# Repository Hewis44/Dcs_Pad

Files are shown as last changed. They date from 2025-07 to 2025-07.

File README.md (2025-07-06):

## DCS World Macropad – “Sukhoi Control Pad” by Hewis Lamilton

## Please Dont consider this as macropad i have made a custom rp2040 for this - its a production level Macropad specially made for music,games




So yeah, I’ve been flying around in DCS World for a while now, mostly in the Su-27 and F/A-18, and it was just super annoying trying to hit 20 keyboard shortcuts every time I wanted to fire a missile, toggle flaps, or adjust trim. I got tired of fumbling keys and decided to just make my own macropad — something that feels like it belongs in a real cockpit. This whole project is my attempt to bring that control panel vibe right onto my desk, with the clickiness and smooth analog feel you only get from physical controls.



I didn’t want to go for those premade macro boards or overpriced HOTAS setups. Instead, I designed my own PCB from scratch using EasyEDA, placed the components carefully, routed everything, added some fighter jet graphics and even stamped my name on it — “MADE BY HEWIS LAMILTON” — just for that personal flex. The board has 9 mechanical switches arranged in a 3x3 grid and 3 rotary encoders at the top for analog input like radar zoom, trims or throttle. These encoders also have push buttons, so they double as click inputs when needed.




The core of the board is powered by the RP2040 microcontroller, soldered during the PCBA process done at JLCPCB. I skipped the Arduino Pro Micro this time because RP2040 is just too good — it gives more performance, is widely supported, and is future-proof. I got two boards assembled (bottom side SMT) from JLC, which means all the micro stuff and passives are already done, so now I just need to add the switches and encoders by hand. I made the board hotswappable using Kailh sockets, so I can just pop switches in and out without worrying about soldering. Makes life easy, especially if you like experimenting with switch feel.







The case design was done in Fusion 360 and looks pretty sleek — all black, with curved corners and a low profile. I’ll probably 3D print it with matte black PLA or maybe even make it from leftover acrylic sheets from my old FPV drone projects. The USB port is Type-C, of course micro-USB is mid and breaks too often. And yes, I’m flashing it with QMK firmware once it arrives. Since QMK now supports RP2040, I can map each key and encoder action to whatever DCS command I want — radar lock, missile launch, you name it.



###  Bill of Materials (Premium Build – ₹11,180 / $124.05)

| **Component** | **Source & Link** | **Qty** | **Total Cost (INR)** | **Total Cost (USD)** |
|---|---|---:|---:|---:|
| Rotary Encoders | [neomacro.in](https://neomacro.in) | 3 | ₹630 | $7.40 |
| Encoder Knobs (Metal) | [neomacro.in](https://neomacro.in) | 3 | ₹270 | $3.17 |
| Mechanical Switches (Gateron G Pro 3.0) | [Amazon.in – Gateron Blue (72-pack)](https://www.amazon.in/dp/B0C6V34QMW) | 9 | ₹663 | $7.80 |
| Hot-swap Sockets (Kailh) | [neomacro.in](https://neomacro.in) | 9 | ₹450 | $5.30 |
| Keycaps (PBT Black/Grey) | [neomacro.in](https://neomacro.in) | 9 | ₹670 | $7.90 |
| Custom PCB (5 pcs) | [neomacro.in](https://neomacro.in) – powered by JLCPCB | 5 | ₹1,950 | $23.39 |
| PCBA (SMT) (2 pcs) |  JLCPCB | 1 | ₹3,550 | $42.47 |
| Shipping (Combined) | Jlcpcb | 1 | ₹1,770 | $21.20 |
| Case (OPTIONAL 3D Printed Frame) | PLA FILAMENT( HAVE PRINTER) | 1 | ₹600 | $7.50 |
---

###  **Total Cost**

**INR:** ₹11,180  
**USD:** $124.05



The total estimated cost of the entire build comes out to approximately $123.68, which in Indian rupees is roughly ₹10,600 based on a dollar rate of ₹85. This includes everything — PCB fabrication, PCBA service, components, and shipping.

Visually, it looks super clean. The PCB has black solder mask, aircraft graphics on the silkscreen, and that Sukhoi logo adds serious style. It's not just a functional tool — it actually looks like a part of the cockpit. The renders turned out mad good too, and I can already imagine how cool it’ll feel mounted next to my keyboard during a dogfight.

To be honest, this is not just a project. It’s a passion piece. Built from scratch, by hand, with desi jugaad and late-night soldering vibes. It's for those moments when you're mid-air in DCS and want a smooth, no-nonsense interface to interact with your aircraft. This macropad adds soul to the sim. 

[ANIMATION.webm](https://github.com/user-attachments/assets/f4643310-f5c0-4364-adad-6bed1c14704e)

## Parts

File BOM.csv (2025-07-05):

Component | Source & Link | Qty | Total Cost (INR) | Total Cost (USD)
Rotary Encoders | https://neomacro.in | 3 | 630 | 7.40
Encoder Knobs (Metal) | https://neomacro.in | 3 | 270 | 3.17
Mechanical Switches (Gateron G Pro 3.0) | https://www.amazon.in/dp/B0C6V34QMW | 9 | 663 | 7.80
Hot-swap Sockets (Kailh) | https://neomacro.in | 9 | 450 | 5.30
Keycaps (PBT Black/Grey) | https://neomacro.in | 9 | 670 | 7.90
Custom PCB (5 pcs) | https://neomacro.in | 5 | 1950 | 23.39
PCBA (SMT) (2 pcs) | JLC | 1 | 3550 | 42.47
Shipping (Combined) | JLC | 1 | 1770 | 21.20
Case (PLA frame)(optional) | HAVE Printer( filament) | 1 | 600 | 7.50
Total |  |  | 11180 | 124.05

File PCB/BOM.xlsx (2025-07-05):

No. | Quantity | Comment | Designator | Footprint | Value | Manufacturer Part | Manufacturer | Supplier Part | Supplier
1 | 7 | 2.2uF | C101,C105,C106,C107,C201,C202,C207 | C0402 | 2.2uF | CL05A225MQ5NSNC | SAMSUNG(三星) | C12530 | LCSC
2 | 21 | 100nF | C102,C103,C104,C108,C109,C113,C114,C115,C116,C125,C126,C127,C210,C211,C212,C213,C214,C215,C216,C217,C218 | C0402 | 100nF | CL05B104KO5NNNC | SAMSUNG(三星) | C1525 | LCSC
3 | 4 | 1uF | C110,C111,C118,C119 | C0402 | 1uF | CL05A105KA5NQNC | SAMSUNG(三星) | C52923 | LCSC
4 | 1 | 47uF | C112 | C1206 | 47uF | CL31A476MPHNNNE | SAMSUNG(三星) | C96123 | LCSC
5 | 2 | 15pF | C123,C124 | C0402 | 15pF | CL05C150JB5NNNC | SAMSUNG(三星) | C86285 | LCSC
6 | 6 | 10nF | C203,C204,C205,C206,C208,C209 | C0402 | 10nF | CL05B103KB5NNNC | SAMSUNG(三星) | C15195 | LCSC
7 | 4 | GG0402052R542P | D101,D102,D103,D104 | D0402-BI |  | GG0402052R542P | Kyocera AVX | C1973257 | LCSC
8 | 12 | 1N5819WS | D201,D202,D203,D204,D205,D206,D207,D208,D209,D210,D211,D212 | SOD-323_L1.8-W1.3-LS2.5-RD |  | 1N5819WS | Hottech(合科泰) | C191023 | LCSC
9 | 3 | PEC12R-4120F-S0012 | ENC201,ENC202,ENC203 | SW-TH_PEC12R-4120F-S0012_1 |  | PEC12R-4120F-S0012 | BOURNS | C143801 | LCSC
10 | 1 | TYPE-C 16PIN 2MD(073) | J101 | USB-C-SMD_TYPE-C-6PIN-2MD-073 |  | TYPE-C 16PIN 2MD(073) | SHOU HAN(首韩) | C2765186 | LCSC
11 | 9 | CPG151101S11-16 | J201,J202,J203,J204,J205,J206,J207,J208,J209 | SMD_KEYBOARD-SW_1 |  | CPG151101S11-16 | Kailh(凯华) | C5156480 | LCSC
12 | 1 | NH-B1010RGBT-HF | LED101 | LED-ARRAY-SMD_4P-L1.0-W1.0-TR_NH-B1010RGBT_1 |  | NH-B1010RGBT-HF | 国星光电 | C2874113 | LCSC
13 | 1 | KT-0805G | LED102 | LED0805-R-RD |  | KT-0805G | KENTO | C2297 | LCSC
14 | 1 | KT-0805Y | LED103 | LED0805-R-RD |  | KT-0805Y | KENTO | C2296 | LCSC
15 | 9 | SK6812MINI-E | LED201,LED202,LED203,LED204,LED205,LED206,LED207,LED208,LED209 | LED-SMD_L3.2-W2.8-TR |  | SK6812MINI-E | 欧思科光电 | C5149201 | LCSC
16 | 1 | 200Ω | R101 | R0402 | 200Ω | 0402WGF2000TCE | UNI-ROYAL(厚声) | C25087 | LCSC
17 | 1 | 100mΩ | R102 | R1206 | 100mΩ | 1206W4F100LT5E | UNI-ROYAL(厚声) | C25334 | LCSC
18 | 7 | 1kΩ | R103,R104,R105,R106,R107,R121,R124 | R0402 | 1kΩ | 0402WGF1001TCE | UNI-ROYAL(厚声) | C11702 | LCSC
19 | 7 | 27Ω | R108,R109,R110,R111,R112,R117,R125 | R0402 | 27Ω | 0402WGF270JTCE | UNI-ROYAL(厚声) | C25100 | LCSC
20 | 4 | 0Ω | R113,R114,R115,R116 | R0402 | 0Ω | 0402WGF0000TCE | UNI-ROYAL(厚声) | C17168 | LCSC
21 | 2 | 5.1kΩ | R118,R119 | R0402 | 5.1kΩ | 0402WGF5101TCE | UNI-ROYAL(厚声) | C25905 | LCSC
22 | 13 | 10kΩ | R123,R201,R202,R203,R204,R205,R206,R207,R208,R209,R210,R211,R212 | R0402 | 10kΩ | 0402WGF1002TCE | UNI-ROYAL(厚声) | C25744 | LCSC
23 | 2 | TS-1187A-B-A-B | SW101,SW102 | SW-SMD_4P-L5.1-W5.1-P3.70-LS6.5-TL-2 |  | TS-1187A-B-A-B | XKB Connectivity(中国星坤) | C318884 | LCSC
24 | 9 | CPG151101S21 | SW201,SW202,SW203,SW204,SW205,SW206,SW207,SW208,SW209 | KEY-TH_CPG1511F01S0X_1 |  | CPG151101S21 | Kailh(凯华) | C404351 | LCSC
25 | 1 | RP2040 | U101 | LQFN-56_L7.0-W7.0-P0.4-EP_1 |  | RP2040 | Raspberry Pi(树莓派) | C2040 | LCSC
26 | 1 | LM3940IMP-3.3/NOPB | U102 | SOT-223_L6.5-W3.5-P2.30-LS7.0-BR |  | LM3940IMP-3.3/NOPB | TI(德州仪器) | C140319 | LCSC
27 | 1 | SN74LV1T34DBVR | U103 | SOT-23-5_L2.9-W1.6-P0.95-LS2.8-BR |  | SN74LV1T34DBVR | TI(德州仪器) | C100024 | LCSC
28 | 1 | W25Q128JVSIQ | U104 | SOIC-8_L5.3-W5.3-P1.27-LS8.0-BL |  | W25Q128JVSIQ | WINBOND(华邦) | C97521 | LCSC
29 | 1 | ABM8-272-T3 | Y101 | CRYSTAL-SMD_4P-L3.2-W2.5-BL |  | ABM8-272-T3 | ABRACON | C20625731 | LCSC

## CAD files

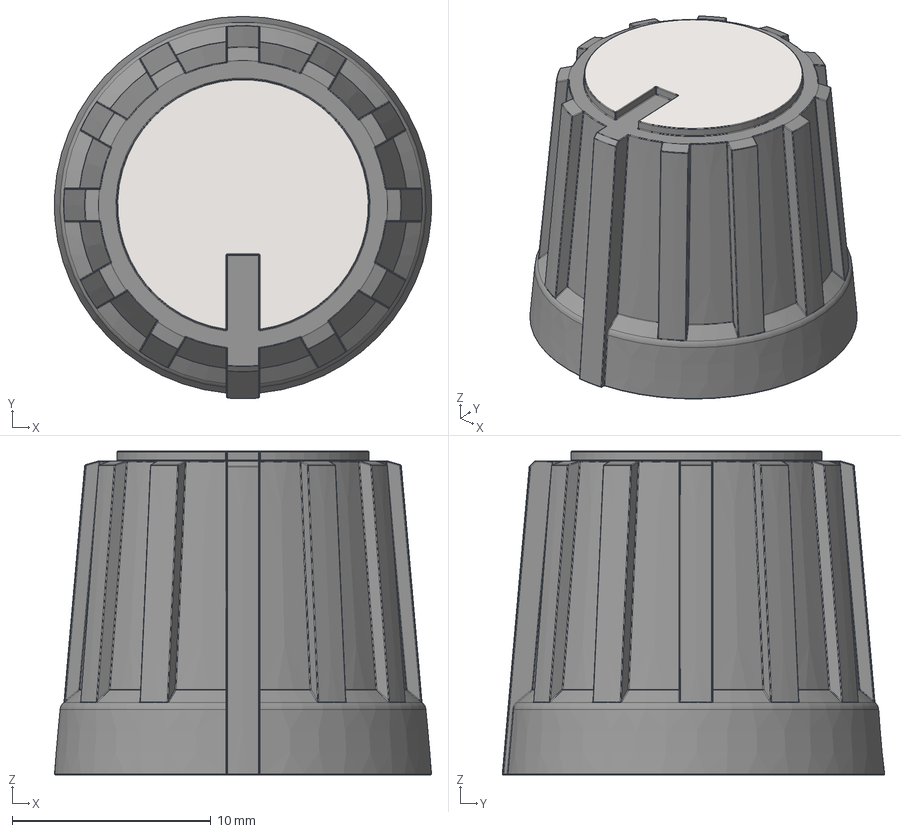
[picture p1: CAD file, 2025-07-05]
CAD/KNOB.step
19.0 x 19.2 x 16.3 mm

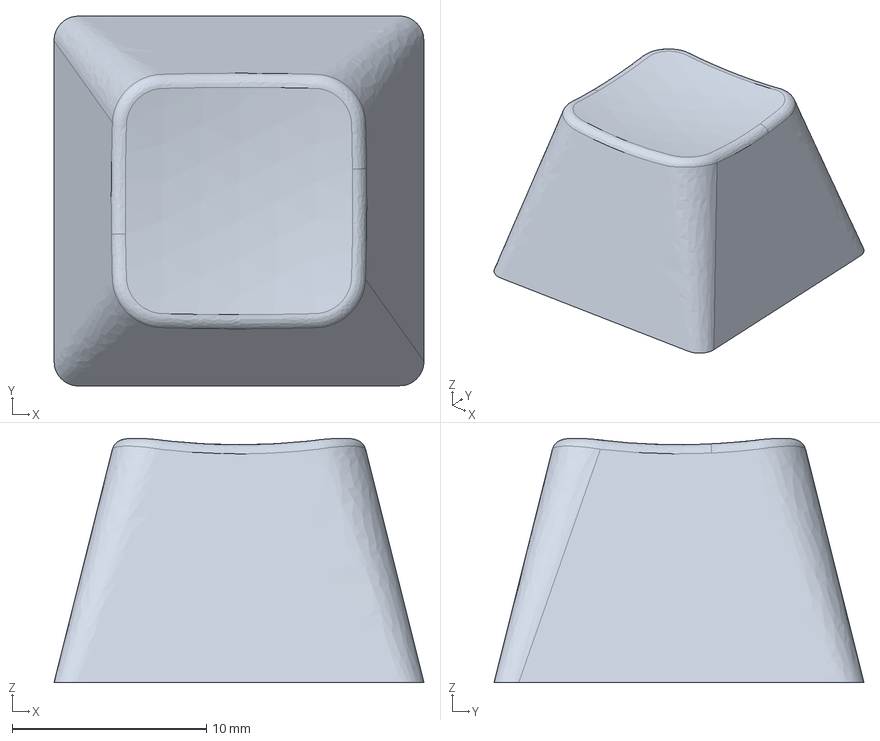
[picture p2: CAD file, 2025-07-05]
CAD/keycap.step
19.1 x 19.0 x 12.6 mm

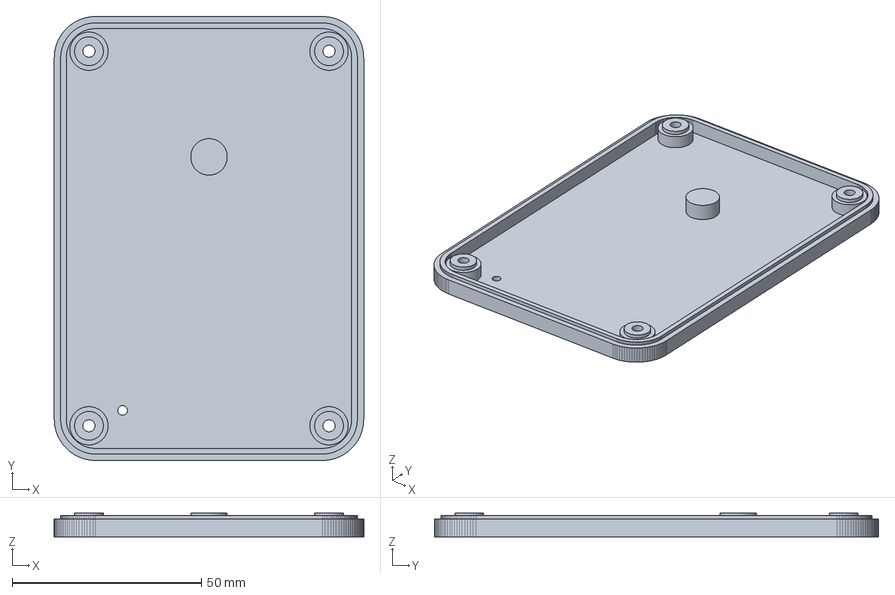
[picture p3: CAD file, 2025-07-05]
CAD/BASE.step
81.9 x 117.4 x 6.32 mm

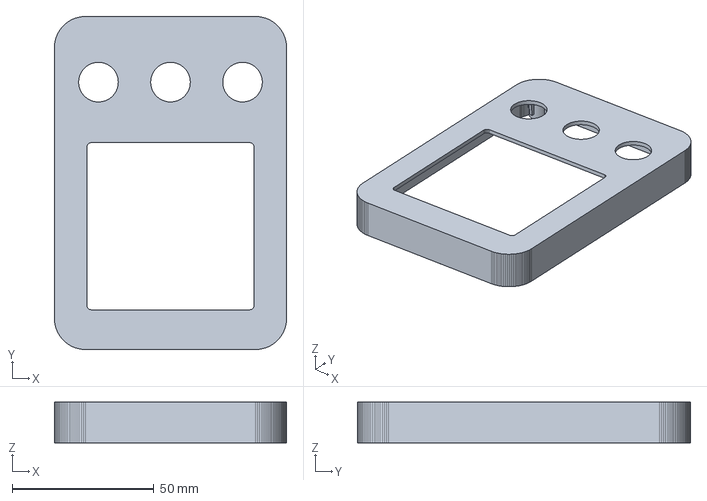
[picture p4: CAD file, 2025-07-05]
CAD/TOP.step
81.9 x 117.4 x 14.4 mm

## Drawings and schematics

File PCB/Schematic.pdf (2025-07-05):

# 5V to 3.3V

# Rasp

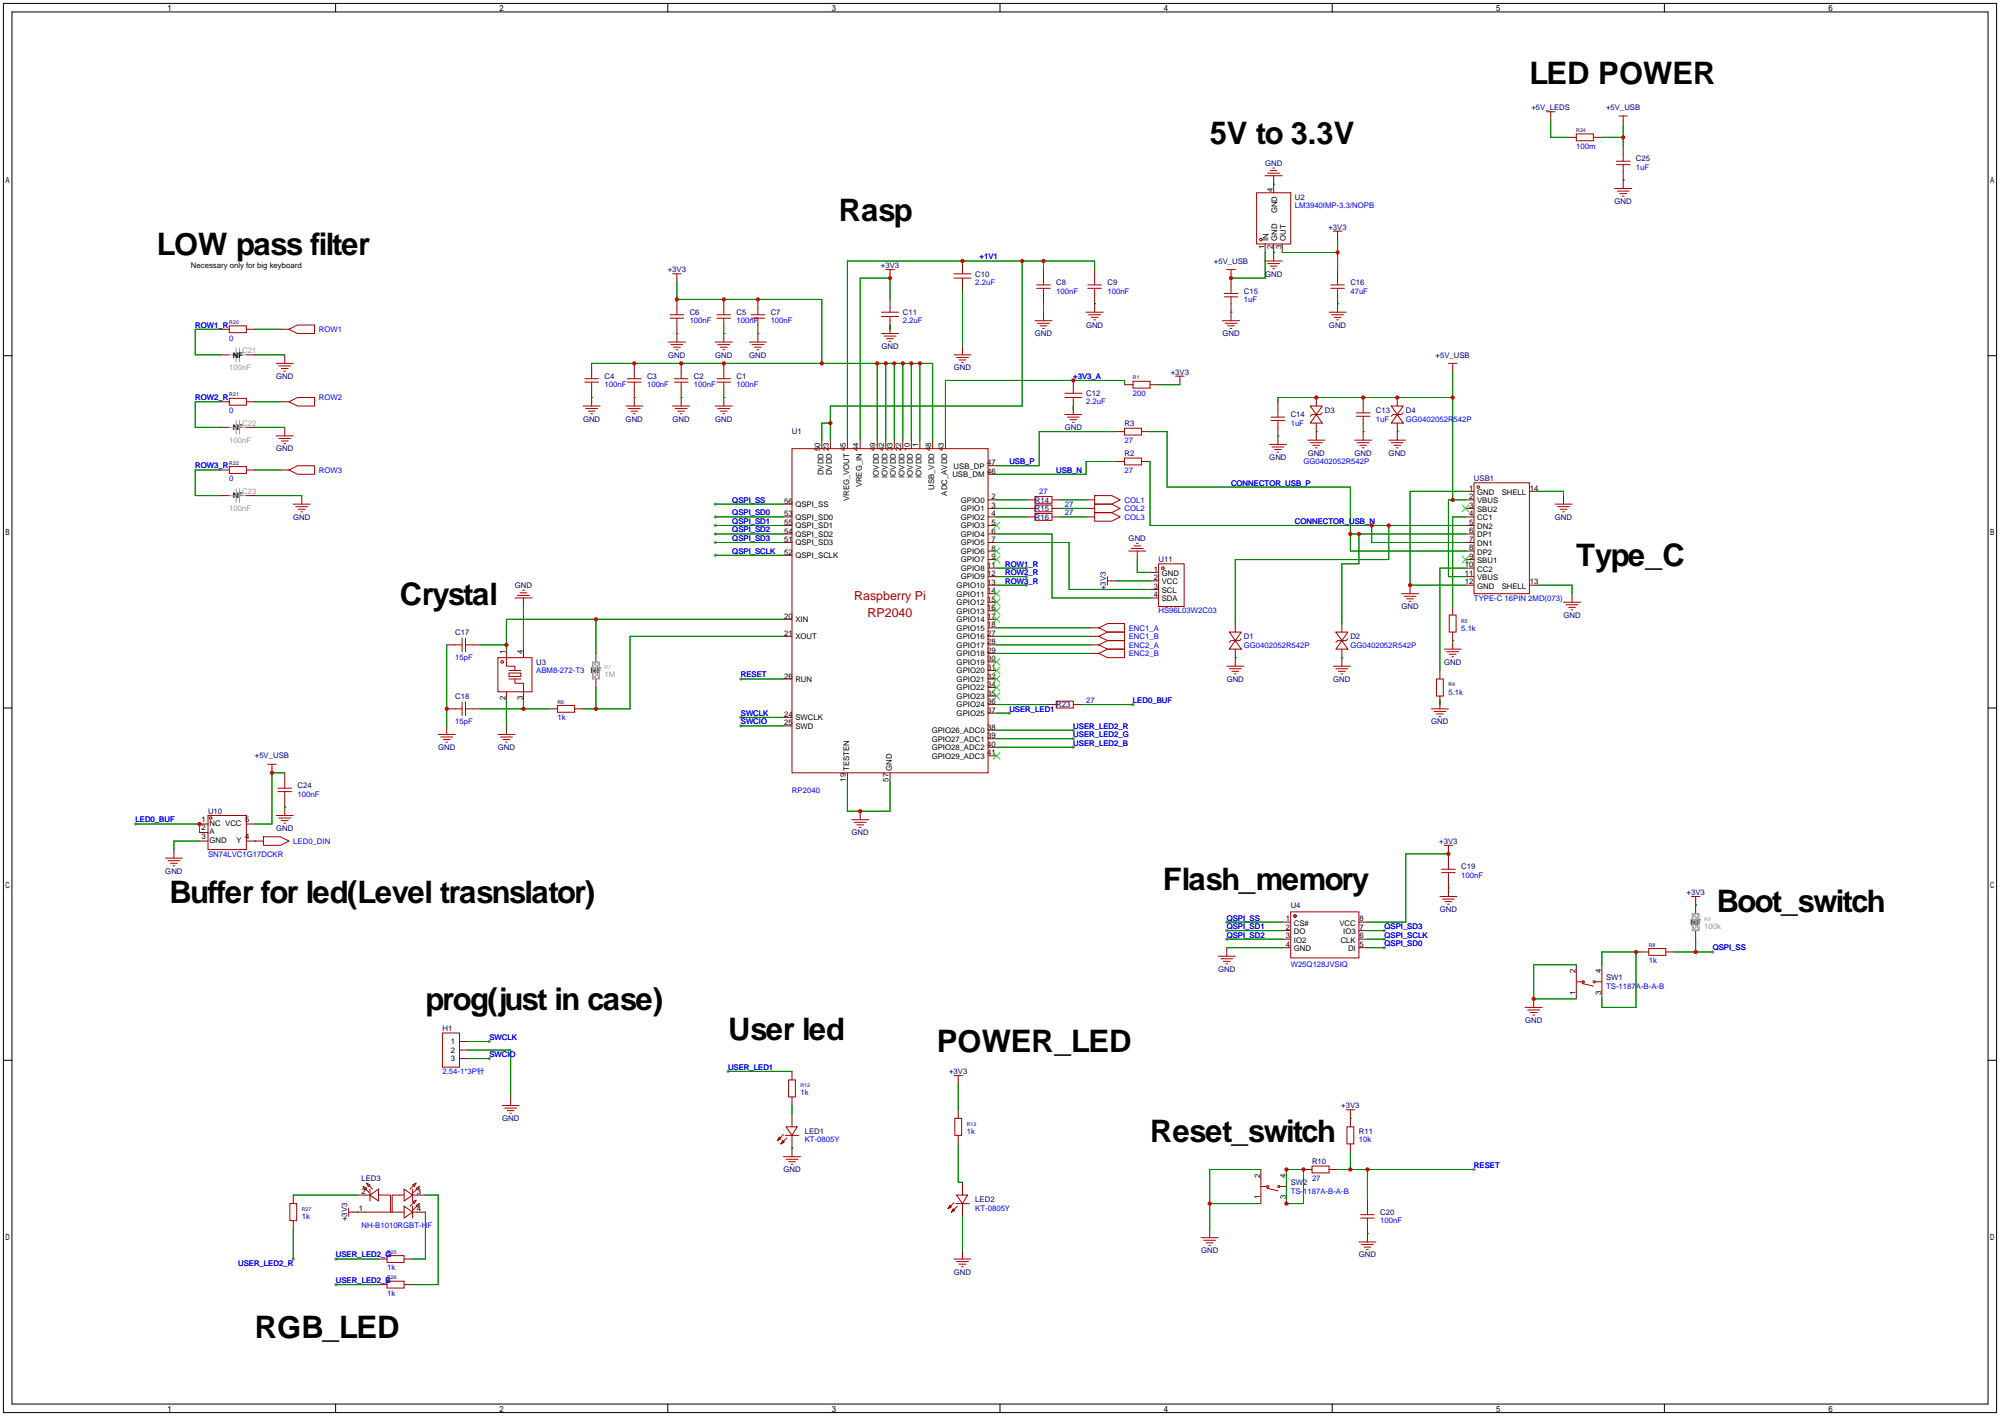
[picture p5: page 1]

Necessary only for big keyboard

prog(just in case)

# LED

# HOLES

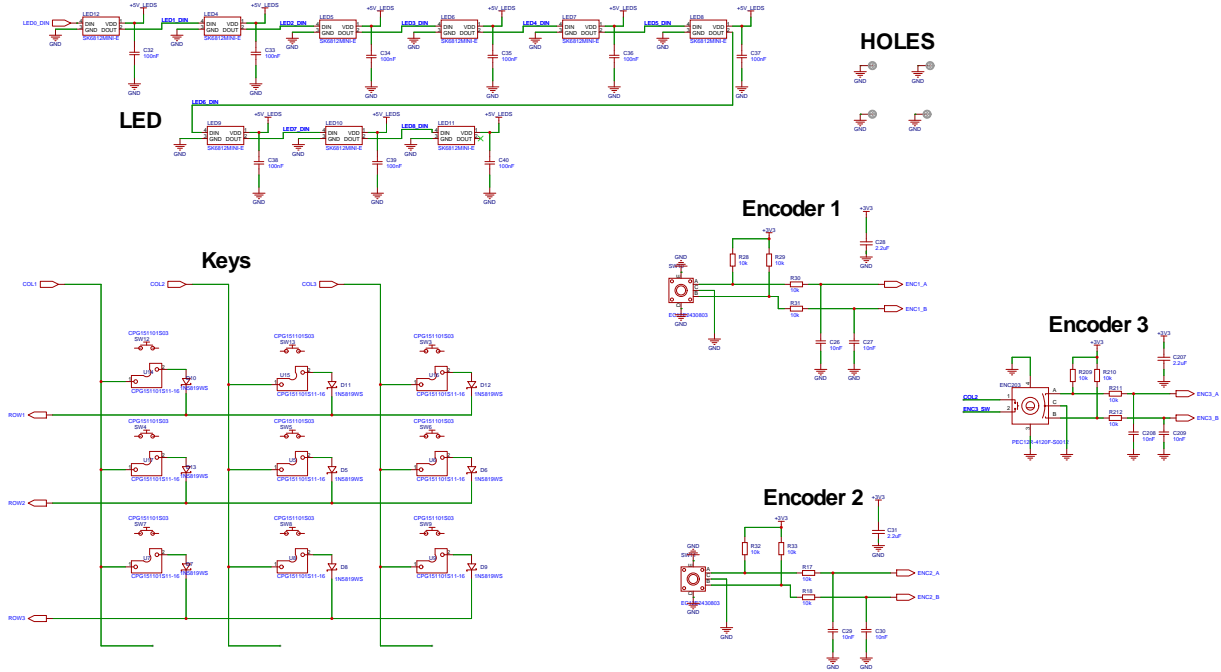
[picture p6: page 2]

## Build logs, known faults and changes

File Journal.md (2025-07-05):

---
Title: "custom RP2040 Macropad"
Author: "Hewis44"
Description: "Everyone using xiao , imma make my own rp2040"
created_at: "2025-07-01"
Total time spent: 21.5
---

## July 1 – Idea , PCB , Design (7 hours)

This whole thing sparked late one night after a long DCS sortie where I totally missed deploying flares because my fingers got tangled on the keyboard. That was the final straw. I kept thinking — how sick would it be to have a small dedicated control panel, with actual mechanical switches and encoders, that feels like a real cockpit module? Not those readymade gaming keypads, but something I could build, tune, and proudly say “I made this.” So yeah, mission initiated.



Started sketching out layout ideas. Wanted it to be compact  something that fits in one hand but still gives you control over essentials like radar, ECM, flaps, trim, weapon select etc. I settled on 9 switches in a 3x3 matrix and 3 rotary encoders up top. The encoders are for zooming, camera view, and trimming. Honestly, this layout hit that sweet spot  balanced and flight-friendly.



For the brain, I instantly chose the RP2040. Bro, Pro Micro is outdated now RP2040 has more GPIOs, handles USB-C better, and it works with QMK now. I dropped the footprint into EasyEDA, added decoupling caps (100nF), a 12MHz crystal with 15pF caps, and proper filtering on power rails. I also added an external W25Q128 QSPI flash chip — you need this on RP2040 since it has no internal storage.



This yt bro guided me to make the microcontroller PCB







Bro made a macropad exactly like i wanted imma start making based on his schematic and his yt tutorial



The USB-C part was fun to figure out. Added ESD protection diodes, 5.1k resistors on CC lines, and used a linear LM3940 regulator to step 5V to 3.3V. I threw in a Power LED with a 1kΩ resistor for vibes — gotta see something glow when you plug it in na?

By the end of the day, I had a working schematic. RP2040, crystal, USB-C, flash, power, decoupling  everything sorted. I felt good about the foundation. The plan was locked, and my PCB journey had officially begun.

## July 2 – matrix,encoders and routing Chaos (8.5-10 hours)

Woke up with pure dev energy. Had chai, threw on some Lofi beats, and jumped into circuit finalization. Today’s mission: build the matrix logic, add the rotary encoders, and somehow route all this chaos into a neat two-layer PCB. Little did I know I’d be crying over vias by the end.



Started with the key matrix 3 rows, 3 columns. Every key sits between a row and a column with a 1N4148 diode to prevent ghosting. Pretty standard stuff. Each line connects to the RP2040 directly. I gave rows 0Ω resistors just in case I wanna break them out externally later. The column lines I routed through the bottom layer  space saver.



Next came the encoders. I used those classic EC11-type rotary encoders. Each one gives two outputs (A/B) for direction and a push button in the middle. For debounce, I added 10k pull-up resistors and 10nF filter caps to GND. The encoder lines eat up a lot of GPIOs — six for A/B, and three more for switch presses  but RP2040 had enough to spare.



Then I added the WS2812 LEDs for some cockpit underglow. These take 5V and expect a strong digital signal. RP2040 outputs 3.3V, so I added a SN74LVC1G17 buffer to step it up. DIN goes in, and the first LED gets clean 5V logic. Each LED also has a 100nF ceramic cap close by for stability.



The routing part was MAD. With switch matrix, encoder lines, power rails, LED tracks  my board looked like spaghetti at one point. Had to slow down, push traces around manually, and optimize for minimum vias. I used wider traces for power lines, threw down GND planes on both layers, and added mounting holes for a future case AS HELPED BY ROBERT THE PCB GUY ON YT. 



ADDED SILKSCREEN OBVIOUSLY

Ended the day mentally drained but proud  my PCB was ready to order.

## July 3 – BOM Breakdown, Firmware Work & Case Prep (4.5 hours)



Today was more chill but still packed with essential stuff. First thing I did was sit and finalize the Bill of Materials (BOM). I hit up neomacro.in and Amazon.in, comparing prices and matching part numbers. Found a 72-pack of Gateron Blue switches on Amazon for around ₹5,300 — used 9 for this build, so ₹663 went into the BOM. The Kailh hot-swap sockets were on neomacro for ₹450. The rotary encoders I grabbed from Robu.in for about ₹210 each. Diodes and resistors came from my local box of components.



Next, I went to JLCPCB via neomacro and uploaded the Gerbers. Ordered 5 PCBs (black soldermask, HASL finish), and also did PCBA for 2 boards with RP2040, USB-C, flash, all passives soldered. Saved me a ton of time — hand soldering QFN chips is hell. Total JLC cost with shipping came around ₹9,050. Shipping alone was ₹2,036 but worth it for DHL  I want this thing before the weekend, not next month.











Then I opened Fusion 360 and designed the outer shell. Simple box-type case with cutouts for USB, encoders, and key caps. Added screw posts, snapped dimensions tight, and left some room for a future acrylic top panel. Planning to 3D print it in black PLA.

i ALSO TRIED ANIMATIONS( VERY BAD)



[ANIMATION.webm](https://github.com/user-attachments/assets/8ee8b1c9-feb6-40c3-911c-d5dce06c1714)

I HOPE THIS GETS APPROVED AND IT WILL GET ME MORE POINTS SO THAT I CAN COME TO UNDERCITY :)
